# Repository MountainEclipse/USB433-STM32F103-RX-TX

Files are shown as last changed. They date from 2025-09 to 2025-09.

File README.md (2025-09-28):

# USB433 - Sniff and Transmit

USB-connected, STM32F103-based 433.92MHz module with asynchronous RX sniffing for OOK protocol

<hr>

*Github Repo: <a href="https://github.com/MountainEclipse/USB433-STM32F103-RX-TX" target="_blank">USB433</a> by <a href="https://github.com/MountainEclipse" target="_blank">MountainEclipse (TimeHack)</a>*

*Assembly Instructable: <a href="https://www.instructables.com/USB433-Sniff-Transmit-OOK-43392-MHz/" target="_blank">USB433 - Sniff & Transmit OOK 433.92 MHz</a>*

<hr>

This project allows you to passively sniff On-Off-Keyed (OOK) signals in the environment - up to 64 bits in length - and transmit OOK messages via a USB-connected radio module. Originally designed to operate 433.92 MHz wireless outlet switches, this module can also receive weather station data and mimic other 433 MHz codes.

Designed to operate on a custom circuit board, this project should equally work with the hobby-friendly BluePill STM32F103 board with jumper wires to OOK RX/TX modules. All design and firmware files are provided as is, for personal hobbyist use under Creative Commons 4.0 Attribution, Non-Commercial (CC BY-NC) international license.

The following is a list of everything you need to make this project:
<ul>
  Hardware:

<li>STM32F103 Microcontroller (the STM32 Blue Pill can work; just pay attention to pinouts)</li>
<li>433 MHz OOK Receiver and Transmitter (I used SRX882 and STX882)</li>
<li>Optional: 3D Printer for printing the enclosure</li>
<li>Optional: LED's for user feedback</li>
<li>4x M3x12 hex socket screws</li>
<li>4x M3 hex nuts</li>
</ul>
<ul>
Software:
<li>KiCAD 6.0 (If you're modifying the PCB or generating the DRL files for PCB fabrication)</li>
<li>STM32CubeIDE (for flashing the STM32 with ease)</li>
<li>Optional: Hercules Setup Utility (for testing serial commands)</li>
</ul>

<hr>
For instructions on assembly, flashing, and testing, please visit the project Instructable <a href="https://www.instructables.com/USB433-Sniff-Transmit-OOK-43392-MHz/" target="_blank">here</a>

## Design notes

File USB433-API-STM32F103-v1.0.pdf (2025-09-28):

# STM32F103 433MHz RX/TX Module

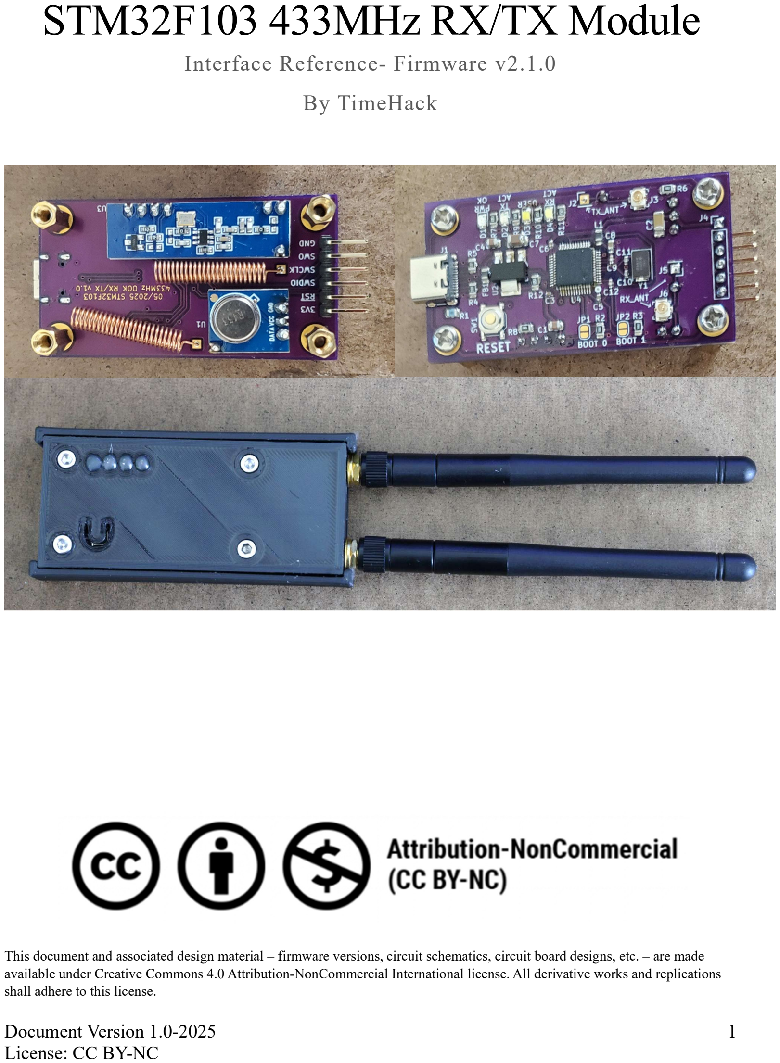
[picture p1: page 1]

Document Version 1.0-2025 | 1
License: CC BY-NC

Interface Reference- Firmware v2.1.0 By TimeHack

This document and associated design material – firmware versions, circuit schematics, circuit board designs, etc. – are made available under Creative Commons 4.0 Attribution-NonCommercial International license. All derivative works and replications shall adhere to this license.

Document Version 1.0-2025 | 2

## Summary

This module is a USB-driven RF sniffer and transmitter module based around the SRX882S and STX882 Superheterodyne Receiver/Transmitter pair and an STM32F103C8T6 processor. Both receive and transmit operations are highly configurable by the user via USB serial communications port.

The module is designed to connect to a USB host device with the default Communications Device Class (CDC) driver. A user can then open a serial port to the module to configure receive/transmit parameters, command transmissions, and receive asynchronous messages about sent and received transmissions.

When idle, the module passively listens for changes to the data output from the SRX882S Receiver, collecting information about on/off pulse widths and periods and correlating received data to measure repetitions of bit sequences (“words”) to indicate a data transmission. Each correlated word (up to 64 bits in length) then gets communicated to the USB host with additional information regarding word length, waveform timings (high/low/period durations), and receiver parameters (logic assumption, whether an initial sync bit is ignored). The module can be configured to listen for words within a range of lengths, from 1 to 64 bits.

The module can transmit messages up to 64 bits in length with an optional leading synchronizing bit, which is a long-high duration pulse (typically a 0 for standard logic interpretations). That synchronizing bit is automatically added to the transmission payload if the ignoresyncbit flag is set false (0).

The module includes LED’s for user feedback. One indicates 3.3V available to the processor core and RX/TX modules; a second indicates USB activity and illuminates upon user commands to the units and asynchronous messages from the module; the third indicates transmission activity, and the fourth represents whether the receiver module is active.

Document Version 1.0-2025 | 3

## System Status Codes

The internal system status variable consists of a single, 32-bit unsigned integer, divided into four bytes. Values from bits 0-7 are reserved for USB status codes; bits 8-15 represent transmission status codes; bits 16-23 are for receiver status codes; and bits 24-31 are reserved for future expansion.

A complete listing of utilized status codes are shown in Table 1. Status codes beginning with USB_CC are used in USB responses to commands, whereas status codes starting with RX and TX are used in asynchronous messages to the USB host. The status code will always be the first value in a message string from the module. See the following subsections for detail on each status code.

Table 1: Hex and Decimal codes for system statuses
Code Identifier | Byte Value (Hex) | Status Value (Decimal)
USB_CC_OK | 0x00 | 0
USB_CC_BUSY | 0x01 | 1
USB_CC_UNKNOWN | 0x10 | 16
USB_CC_BAD_VALUE | 0x20 | 32
USB_CC_BAD_PARAM | 0x30 | 48
USB_CC_MISSING_PARAM | 0x31 | 49
TX_BUFFER_EMPTY | 0x0100 | 256
TX_PREP_FAILED | 0x0200 | 512
TX_COMPLETE | 0x0400 | 1024
RX_WORD_AVAILABLE | 0x010000 | 65536

### USB_CC_OK

Response provided after successful get or set USB operation. When setting parameters, a response of ‘0 OK’ will be sent. For getting parameters, a response ‘0 <parameter> <value>’ will be sent, where ‘parameter’ is the final word of the command (e.g. ‘mode’ for ‘rx mode’; or, ‘short’ for ‘tx time short’) and ‘value’ is the current parameter value. Single-word commands return ‘0 <value>’ for the current parameter value (e.g. ‘version’ returns ‘0 2.1.0’; and, ‘status’ returns ‘0 <status>’).

### USB_CC_BUSY

Response provided when the module is busy processing and cannot execute the requested command. As of the current firmware version (2.1.0), this response is only provided if the transmission word buffer is full and cannot accept another call to ‘tx [word]’. Such a response is only the status code.

Document Version 1.0-2025 | 4

### USB_CC_UNKNOWN

Response provided when the provided command is not recognized – essentially if the first word in the command string is not ‘rx’, ‘tx’, ‘status’, or ‘version’. Response follows structure: ‘<status> <command>’ where ‘command’ is the unrecognized part of the command string.

### USB_CC_BAD_VALUE

Response provided when the value given for setting a parameter is invalid for the command. The value may be out of the range limitations internal to the system or the wrong data type. Response format follows ‘<status> <invalid_value>’, where ‘invalid_value’ is the problematic value.

### USB_CC_BAD_PARAM

Response provided when parts of the command are recognized, but a subcommand is invalid. Response structure is formatted as ‘<status> <bad_subcommand>’ where ‘bad_subcommand’ is the problematic string. For example, if the command ‘rx data’ is passed, the command ‘rx’ is recognized, but ‘data’ is invalid, so the module will respond with ’48 data’.

### USB_CC_MISSING_PARAM

Response to an incomplete command, where all parts are recognized, but it doesn’t correspond to an action for the module to perform due to a missing subcommand or parameter. Response is strictly the status code.

### TX_BUFFER_EMPTY

Status indicating there are no pending transmissions in the buffer. Only available upon request by the USB host using command ‘status’. Synonymous with an idle system status during normal operation.

### TX_PREP_FAILED

A status which should never occur, provided adequate parsing during command processing. This will asynchronously be sent to the USB host if the transmission word being processed for broadcast contains invalid characters – i.e. values that are not ‘0’ or ‘1’. This state is included as a built-in secondary safety against core faults from processing invalid words. Message structure with this asynchronous message follows ‘<status> <tx_word>’, with ‘tx_word’ being the problematic broadcast word.

### TX_COMPLETE

Status message that will be asynchronously sent to the USB host to indicate a transmission has completed successfully. Message structure follows ‘<status> <tx_word>’, with ‘tx_word’ being the binary string successfully broadcast. This string will include any automatically prepended sync bits based on the setting ‘tx ignoresyncbit’.

Document Version 1.0-2025 | 5

### RX_WORD_AVAILABLE

Status message to be asynchronously sent to the USB host when a transmission is received that matches the settings configuration for the receive channel of the module. Detections / matches will only be triggered if all of the following are met:
- Detected bit sequence longer than ‘rx word minlength’
- Detected bit sequence shorter than ‘rx word maxlength’
- Detected repetition of bit sequence greater than or equal to ‘rx word matchcount’
- Time between last bit sequence received and the newest received code is less than
‘rx word timeout’ microseconds. All sequences received prior to an elapsed word reception gap of this timeout will be used to check for word repetitions.
- A bit sequence repetition for this code has not already been transmitted to the USB host in the last ‘rx word timeout’ microseconds.

These conditions mean that for a broadcast word which might be transmitted 10 times to ensure the receiving device reliably receives the word, the USB host device will not be overwhelmed with messages each time a repetition more than ‘rx word matchcount’ occurs in that repeated burst of word transmissions. For each burst, only one transmission of a repeated word will be sent.

Document Version 1.0-2025 | 6

## USB Serial Commands

The module accepts a diversity of commands for getting/setting on-board parameters. Each valid command is defined below. Where the command includes a data type in ‘< >’ at the end, the bracketed value is optional. Including that value uses the write function of that command, and omitting it will execute the read function of that command.

All successful ‘read’ operations will return a message structure
<status> <final_subcommand> <value>
where ‘status’ is USB_CC_OK, ‘final_subcommand’ is the last non-value word of the command string, and ‘value’ is the current parameter value.

All ‘write’ operations, if successful, will return a message structure
<status> OK
with ‘status’ being the value of USB_CC_OK.

Failure statuses will be returned as applicable as defined in the System Status Codes section, and according to limitations described below in the respective commands.

### version

(READ ONLY)
Return the installed firmware version string in format <major>:<minor>:<tweak> (present as of 2.1.0). Major changes overhaul major system operations (core behavior of RX/TX, etc.) which are not compatible with older versions of the firmware; minor changes correspond to compatibility with older firmware versions, but with added features; tweaks are small updates which do not impact interface between the USB host and module, but which modify module behaviors not seen by the user.

### status

(READ ONLY)
Return the current system 'status' value. Status is a 32-bit (4-byte) code with possible values defined in Table 1 in the section System Status Codes.

### rx mode <0:1:2>

(READ / WRITE)
Get or set the current receiver mode.
- 0 = always off: do not listen for asynchronous broadcasts
- 1 = always on: always listen for broadcasts, even during this module’s broadcasts
- 2 = automatic: disable broadcast detection during this module’s broadcasts (DEFAULT)

Default value: 2 (automatic)
Minimum value: 0
Maximum value: 2

Document Version 1.0-2025 | 7

### rx bitperiod <uint32_t>

(READ / WRITE)
Get or set the maximum bit period, in microseconds. This acts as a timeout during broadcast receptions which allows for processing the data buffer. Due to how OOK broadcasts are structured (with a moderate delay between word transmission repetitions), the most efficient execution for the internal system includes this setting being tuned according to the expected bit period timing of the signal to be received.

Default value: 5000 microseconds (5 ms).
Minimum value: 0 (not recommended)
Maximum value: UINT32_MAX (not recommended)

### rx word matchcount <uint8_t>

(READ / WRITE)
Set the minimum number of matching received word transmissions to trigger an asynchronous RX_WORD_RECEIVED message. This number of repetitions indicates the reception as a “valid” word in order to filter erroneous receptions by the system through corruptions or interference with other signals. Maximum value defined by the length of the data correlation buffer.

Default value: 3
Minimum value: 0
Maximum value: 12

### rx word minlength <uint8_t>

(READ / WRITE)
Get or set the minimum word length (in bits) to use in correlating received data. Any words shorter than this limit get discarded. Maximum limit defined by ‘rx word maxlength’.

Default value: 8
Minimum value: 0
Maximum value: rx word maxlength

### rx word maxlength <uint8_t>

(READ / WRITE)
Get or set the maximum word length (in bits) to use in correlating received data. Any words longer than this limit get discarded. Minimum limit defined by ‘rx word minlength’. Maximum limit set by maximum word buffer length.

Default value: 64
Minimum value: rx word minlength
Maximum value: 64

Document Version 1.0-2025 | 8

### rx word timeout <uint32_t>

(READ / WRITE)
Get or set the timeout, in microseconds, for the data correlation buffer which caches the most recently received bit sequences. Once this timeout occurs, the buffer will be cleared. Minimum limit defined by ‘rx bitperiod’.

Default value: 100,000 (100 ms)
Minimum value: rx bitperiod
Maximum value: 5,000,000 (5 s)

### rx ignoresyncbit <0:1>

(READ / WRITE)
Get or set whether the synchronizing bit (first bit received in sequence which sets the receiver state) should be included in the bit sequence to be sent to the USB host.
- 0 = no; include sync bit.
- 1 = yes; omit sync bit.

Default value: 1 (omit sync bit)
Minimum value: 0
Maximum value: 1

### rx logic <0:1>

(READ / WRITE)
Get or set the logic interpretation by the receiver – i.e. how high-low relative durations should be interpreted as bits.
- 0 = long high with short low corresponds to bit ‘0’
- 1 = long high with short low corresponds to bit ‘1’

Default value: 0
Minimum value: 0
Maximum value: 1

### tx time short <uint16_t>

(READ / WRITE)
Get or set the timing, in microseconds, of a short pulse. Used for both logic ‘0’ and ‘1’ short part of bit transmission. Must be less than ‘tx time long’ or UINT16_MAX / 2, whichever is less. The sum of ‘tx time short’ and ‘tx time long’ determines bit period for transmission.

Default value: 300
Minimum value: 0 (not recommended)
Maximum value: tx time long

Document Version 1.0-2025 | 9

### tx time long <uint16_t>

(READ / WRITE)
Get or set the timing, in microseconds, or a long pulse. Used for both logic ‘0’ and ‘1’ long part of bit transmission. Must be greater than ‘tx time short’ and less than UINT16_MAX / 2. The sum of ‘tx time short’ and ‘tx time long’ determines bit period for transmission.

Default value: 700
Minimum value: tx time short
Maximum value: UINT16_MAX / 2

### tx delay frame <uint32_t>

(READ / WRITE)
Get or set the time delay, in microseconds, between sequential transmissions of words within the same frame. Each word transmitted is considered a ‘frame, and is repeated ‘tx repeat’ number of times. This is the delay between each repetition of transmission.

Default value: 6600 (6.6 ms)
Minimum value: [(tx time short) + (tx time long)] (1 bit period)
Maximum value: 50*[(tx time short) + (tx time long)] (50 bit periods)

### tx delay burst <uint32_t>

(READ / WRITE)

Get or set the time delay, in microseconds, between sequential broadcasts of buffered words. Each broadcast is considered a ‘burst’ and consists of ‘tx repeat’ number of frames. This is the delay between different broadcast bursts, and controls how fast sequential broadcast requests can be executed.

Default value: 100,000 (100 ms)
Minimum value: [(tx time short) + (tx time long)]
Maximum value: 60,000,000 (60 s)

### tx ignoresyncbit <0:1>

(READ / WRITE)
Get or set whether a sync bit should be prepended to the bit sequence to transmit. If this is value 1 (true), the user should compensate for sync bit inclusion in the transmitted bit sequence.
- 0 = prepend a ‘0’ bit to the transmission bit sequence
- 1 = do not prepend a ‘0’ to the transmission bit sequence

Default value: 0
Minimum value: 0
Maximum value: 1

Document Version 1.0-2025 | 10

### tx repeat <uint8_t>

(READ / WRITE)
Get or set how many times a bit sequence frame gets repeated in a burst. One frame will always be transmitted. This is the number of repetitions of transmissions.

Default value: 7
Minimum value: 0
Maximum value: 100

### tx logic <0:1>

(READ / WRITE)
Get or set the logic to be used for interpreting commanded broadcasts.
- 0 = ‘0’ means long high with short low
- 1 = ‘1’ means long high with short low

Default value: 0
Minimum value: 0
Maximum value: 1

### tx [sequence of 0:1]

(WRITE ONLY)
Queue the broadcast of a bit sequence, up to 64 bits. Up to 5 messages can be simultaneously queued for transmission and will be processed according to the time separation of ‘tx delay burst’.

Document Version 1.0-2025 | 11

## Asynchronous Messages

Three message types occur asynchronously with user commands. These indicate a broadcast reception, a failure to prepare a transmission burst, or successful completion of a transmission burst. Details on each message structure are below.

### Broadcast Received

Message to indicate a valid broadcast was received. See System Status Codes -> RX_WORD_AVAILABLE for more information on how received broadcasts are validated. The message format for this follows:
<status> word:[0:1] len:<word_len> long_us:<long> short_us:<short> period_us:<period> logic:<logic> ignoresync:<sync>
where:
- ‘status’ is RX_WORD_AVAILABLE
- ‘word_len’ is the length of the received bit sequence
- ‘long’ is the average of long pulse durations across all received matching bit sequences
- ‘short’ is the average of short pulse durations across all received matching bit sequences
- ‘period’ is the average period duration across all received matching bit sequences
- ‘logic’ is the interpretation used to present ‘0’ and ‘1’ characters. See ‘rx logic’ for more information
- ‘sync’ is whether the first received bit (sync bit) is included in the received message. See ‘rx ignoresyncbit’ for more information.

### Transmission Preparation Failed

Message to indicate an error with translating the commanded transmission bit sequence into a sequence of pulses. Namely, a character other than ‘0’ or ‘1’ made it to the buffered bit sequence. Message structure follows:
<status> [word]
where ‘status’ is TX_PREP_FAILED, and ‘word’ is the string which failed to translate into pulses.

### Message Transmitted

Message ton indicate successful transmission of a bit sequence burst. Message structure follows: <status> [word]
where ‘status’ is TX_COMPLETE, and ‘word’ is the binary string successfully transmitted, including prepended sync bit, as applicable.

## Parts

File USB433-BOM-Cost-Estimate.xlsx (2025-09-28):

Tool: | Eeschema (6.0.11)
Component Count: | 44
Ref | Qnty | Value | Cmp name | Footprint | Description | Price | Cost | Vendor | Link
C1, C4, | 2 | 10uF | C | Capacitor_SMD:C_0805_2012Metric | Unpolarized capacitor | $0.0104 | $0.0208 | LCSC | https://www.lcsc.com/product-detail/Multilayer-Ceramic-Capacitors-MLCC-SMD-SMT_Samwha-Capacitor-CS2012X5R106K100NRE_C513765.html
C2, | 1 | 100u | C_Polarized_US | Capacitor_SMD:C_1206_3216Metric_Pad1.33x1.80mm_HandSolder | Polarized capacitor, US symbol | $0.1802 | $0.1802 | LCSC | https://www.lcsc.com/product-detail/Multilayer-Ceramic-Capacitors-MLCC-SMD-SMT_HRE-CGA1206X5R107K6R3NT_C6119960.html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
C3, C5, C6, C9, C12, | 5 | 100nF | C | Capacitor_SMD:C_0402_1005Metric | Unpolarized capacitor | $0.0017 | $0.0085 | LCSC | https://www.lcsc.com/product-detail/Multilayer-Ceramic-Capacitors-MLCC-SMD-SMT_YAGEO-CC0402JRX7R7BB104_C541464.html
C7, | 1 | 22uF | C | Capacitor_SMD:C_1206_3216Metric | Unpolarized capacitor | $0.0248 | $0.0248 | LCSC | https://www.lcsc.com/product-detail/Multilayer-Ceramic-Capacitors-MLCC-SMD-SMT_Samwha-Capacitor-CS3216X5R226M160NRI_C5177178.html
C8, | 1 | 1uF | C | Capacitor_SMD:C_0603_1608Metric | Unpolarized capacitor | $0.0052 | $0.0052 | LCSC | https://www.lcsc.com/product-detail/Multilayer-Ceramic-Capacitors-MLCC-SMD-SMT_Samsung-Electro-Mechanics-CL10A105KB8NNNC_C15849.html
C10, C11, | 2 | 30p | C | Capacitor_SMD:C_0402_1005Metric | Unpolarized capacitor | $0.0012 | $0.0024 | LCSC | https://www.lcsc.com/product-detail/Multilayer-Ceramic-Capacitors-MLCC-SMD-SMT_FH-Guangdong-Fenghua-Advanced-Tech-0402CG300J500NT_C1570.html
D1, D3, D4, | 3 | PWR_OK, DEBUG, RED | LED | LED_SMD:LED_0805_2012Metric | Light emitting diode | $0.0057 | $0.0171 | LCSC | https://www.lcsc.com/product-detail/LED-Indication-Discrete_XINGLIGHT-XL-2012SURC_C965812.html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
D2, | 1 | BLUE | LED | LED_SMD:LED_0805_2012Metric | Light emitting diode | $0.0239 | $0.0239 | LCSC | https://www.lcsc.com/product-detail/LED-Indication-Discrete_BrtLed-Bright-LED-Elec-BL-HB335B-TRB-6_C189307.html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
FB1, | 1 | FerriteBead | FerriteBead | Resistor_SMD:R_0805_2012Metric | Ferrite bead | $0.0041 | $0.0041 | LCSC | https://www.lcsc.com/product-detail/Ferrite-Beads_MetalLions-MLB2012F-391T_C2844594.html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
J1, | 1 | USB-C | USB_C_Receptacle | Connector_USB:USB_C_Receptacle_G-Switch_GT-USB-7010ASV | USB Full-Featured Type-C Receptacle connector | $0.0761 | $0.0761 | LCSC | https://www.lcsc.com/product-detail/USB-Connectors_G-Switch-GT-USB-7010ASV_C2988369.html
J2, J5 | 2 | TX_ANT_EXT, RX_ANT_EXT | Conn_01x01 | Connector_PinHeader_2.54mm:PinHeader_1x01_P2.54mm_Vertical | Generic connector, single row, 01x01, script generated (kicad-library-utils/schlib/autogen/connector/) |  | $0.0000
J3, J6 | 2 | TX_U.FL, RX_U.FL | U_FL-R-SMT_10_ | digikey-footprints:Coax_Conn_U.FL | CONN U.FL RCPT STR 50 OHM SMD | $0.0331 | $0.0662 | LCSC | https://www.lcsc.com/product-detail/Coaxial-Connectors-RF_BAT-WIRELESS-BWU-FL-IPEX1_C5137195.html?s_z=n_UFL
J4, | 1 | DEBUG | Conn_01x06 | Connector_PinHeader_2.54mm:PinHeader_1x06_P2.54mm_Vertical | Generic connector, single row, 01x06, script generated (kicad-library-utils/schlib/autogen/connector/) |  | $0.0000
JP1, | 1 | BOOT0 | SolderJumper_2_Open | Jumper:SolderJumper-2_P1.3mm_Open_RoundedPad1.0x1.5mm | Solder Jumper, 2-pole, open |  | $0.0000
JP2, | 1 | BOOT1 | SolderJumper_2_Open | Jumper:SolderJumper-2_P1.3mm_Open_RoundedPad1.0x1.5mm | Solder Jumper, 2-pole, open |  | $0.0000
L1, | 1 | 27uH | L | Inductor_SMD:L_0805_2012Metric | Inductor | $0.0233 | $0.0233 | LCSC | https://www.lcsc.com/product-detail/Inductors-SMD_XR-XRCM2012J270K-A005_C41368706.html?s_z=n_27uH%2520inductor
R1, | 1 | 1M | R_US | Resistor_SMD:R_0805_2012Metric | Resistor, US symbol | $0.0077 | $0.0077 | LCSC | https://www.lcsc.com/product-detail/Chip-Resistor-Surface-Mount_KOA-Speer-Elec-RK73H2ATTD1004F_C276217.html
R2, R3, R6, R8, | 4 | 10k | R_US | Resistor_SMD:R_0805_2012Metric | Resistor, US symbol | $0.0098 | $0.0392 | LCSC | https://www.lcsc.com/product-detail/Chip-Resistor-Surface-Mount_KOA-Speer-Elec-RK73H2ATTD1002F_C276215.html
R4, R5, | 2 | 5k1 | R_US | Resistor_SMD:R_0805_2012Metric | Resistor, US symbol | $0.0078 | $0.0156 | LCSC | https://www.lcsc.com/product-detail/Chip-Resistor-Surface-Mount_UNI-ROYAL-Uniroyal-Elec-HP05W3F5101T5E_C2759278.html
R7, R9, R10, R11, R12, | 5 | 1k5 | R_US | Resistor_SMD:R_0805_2012Metric | Resistor, US symbol | $0.0102 | $0.0510 | LCSC | https://www.lcsc.com/product-detail/Chip-Resistor-Surface-Mount_YAGEO-RC0805FR-7W1K5L_C606178.html
SW1, | 1 | RESET | SW_Push | User_Custom:SW_Push_1P1T_W6.8mm_H4.6mm | Push button switch, generic, two pins | $0.0122 | $0.0122 | LCSC | https://www.lcsc.com/product-detail/Tactile-Switches_BZCN-TSC006A1526A_C2888882.html
U1, | 1 | STX882S | STX882S | User_Custom:STX882-THT |  | $1.8738 | $1.8738 | Amazon | https://www.amazon.com/AITIAO-Wireless-Control-Transmitter-Receiver/dp/B09KXKSR3V/ref=sr_1_2?sr=8-2
U2, | 1 | AZ1117CH-3.3TRG1 | AZ1117CH-3_3TRG1 | digikey-footprints:SOT-223 | IC REG LINEAR 3.3V 800MA SOT223 | $0.0722 | $0.0722 | LCSC | https://www.lcsc.com/product-detail/Linear-Voltage-Regulators-LDO_Diodes-Incorporated-AZ1117H-3-3TRG1_C110474.html
U3, | 1 | SRX882S | SRX882S | User_Custom:SRX882-THT |  | $1.8738 | $1.8738 | Amazon | https://www.amazon.com/AITIAO-Wireless-Control-Transmitter-Receiver/dp/B09KXKSR3V/ref=sr_1_2?sr=8-2
U4, | 1 | STM32F103C8Tx | STM32F103C8Tx | Package_QFP:LQFP-48_7x7mm_P0.5mm | ARM Cortex-M3 MCU, 64KB flash, 20KB RAM, 72MHz, 2-3.6V, 37 GPIO, LQFP-48 | $1.7009 | $1.7009 | ARROW | https://www.arrow.com/en/products/stm32f103c8t6/stmicroelectronics
Y1, | 1 | 8M, 20pF | Crystal | Crystal:Crystal_SMD_5032-2Pin_5.0x3.2mm | Two pin crystal | $0.2056 | $0.2056 | LCSC | https://www.lcsc.com/product-detail/Crystals_Yangxing-Tech-X50328MSB2GI_C115962.html
 |  |  |  |  |  | Components | $6.3045
 |  |  |  |  |  | Board Fab | $4.7667
 |  |  |  |  |  | Stencil | $9.6900 | $29.07
 |  |  |  |  |  |  | $20.7612 |  |  | PCB Fab | Round | Bulk Cost | Qty
 |  |  |  |  |  |  |  |  |  |  | 1 | $14.30 | 3
 |  |  |  |  |  |  |  |  |  |  | 2
 |  |  |  |  |  |  |  |  |  |  | 3
 |  |  |  |  |  |  |  |  |  |  | 4
 |  |  |  |  |  |  |  |  |  |  | 5
 |  |  |  |  |  |  |  |  |  |  | 6
 |  |  |  |  |  |  |  |  |  |  | 7
 |  |  |  |  |  |  |  |  |  |  | 8
 |  |  |  |  |  |  |  |  |  |  | 9

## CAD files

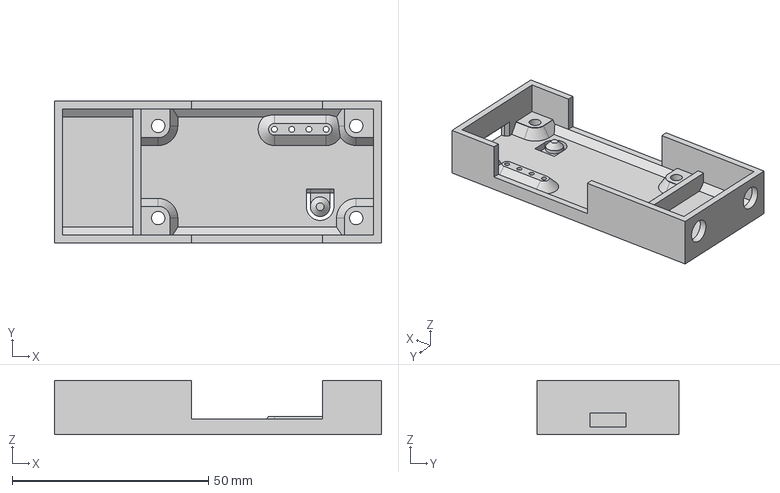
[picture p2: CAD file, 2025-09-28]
USB433-Enclosure-CAD/Bottom.step
83.4 x 36.1 x 13.8 mm

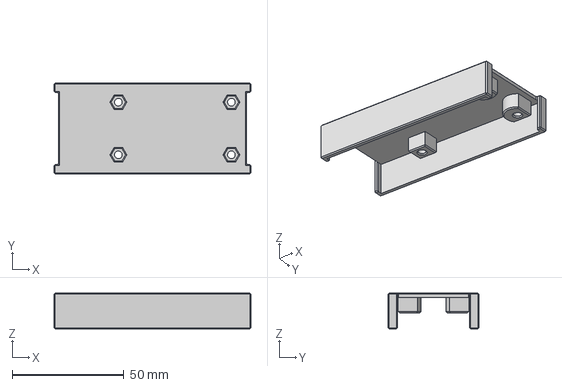
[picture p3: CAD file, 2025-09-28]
USB433-Enclosure-CAD/Top.step
88.0 x 40.7 x 16.0 mm

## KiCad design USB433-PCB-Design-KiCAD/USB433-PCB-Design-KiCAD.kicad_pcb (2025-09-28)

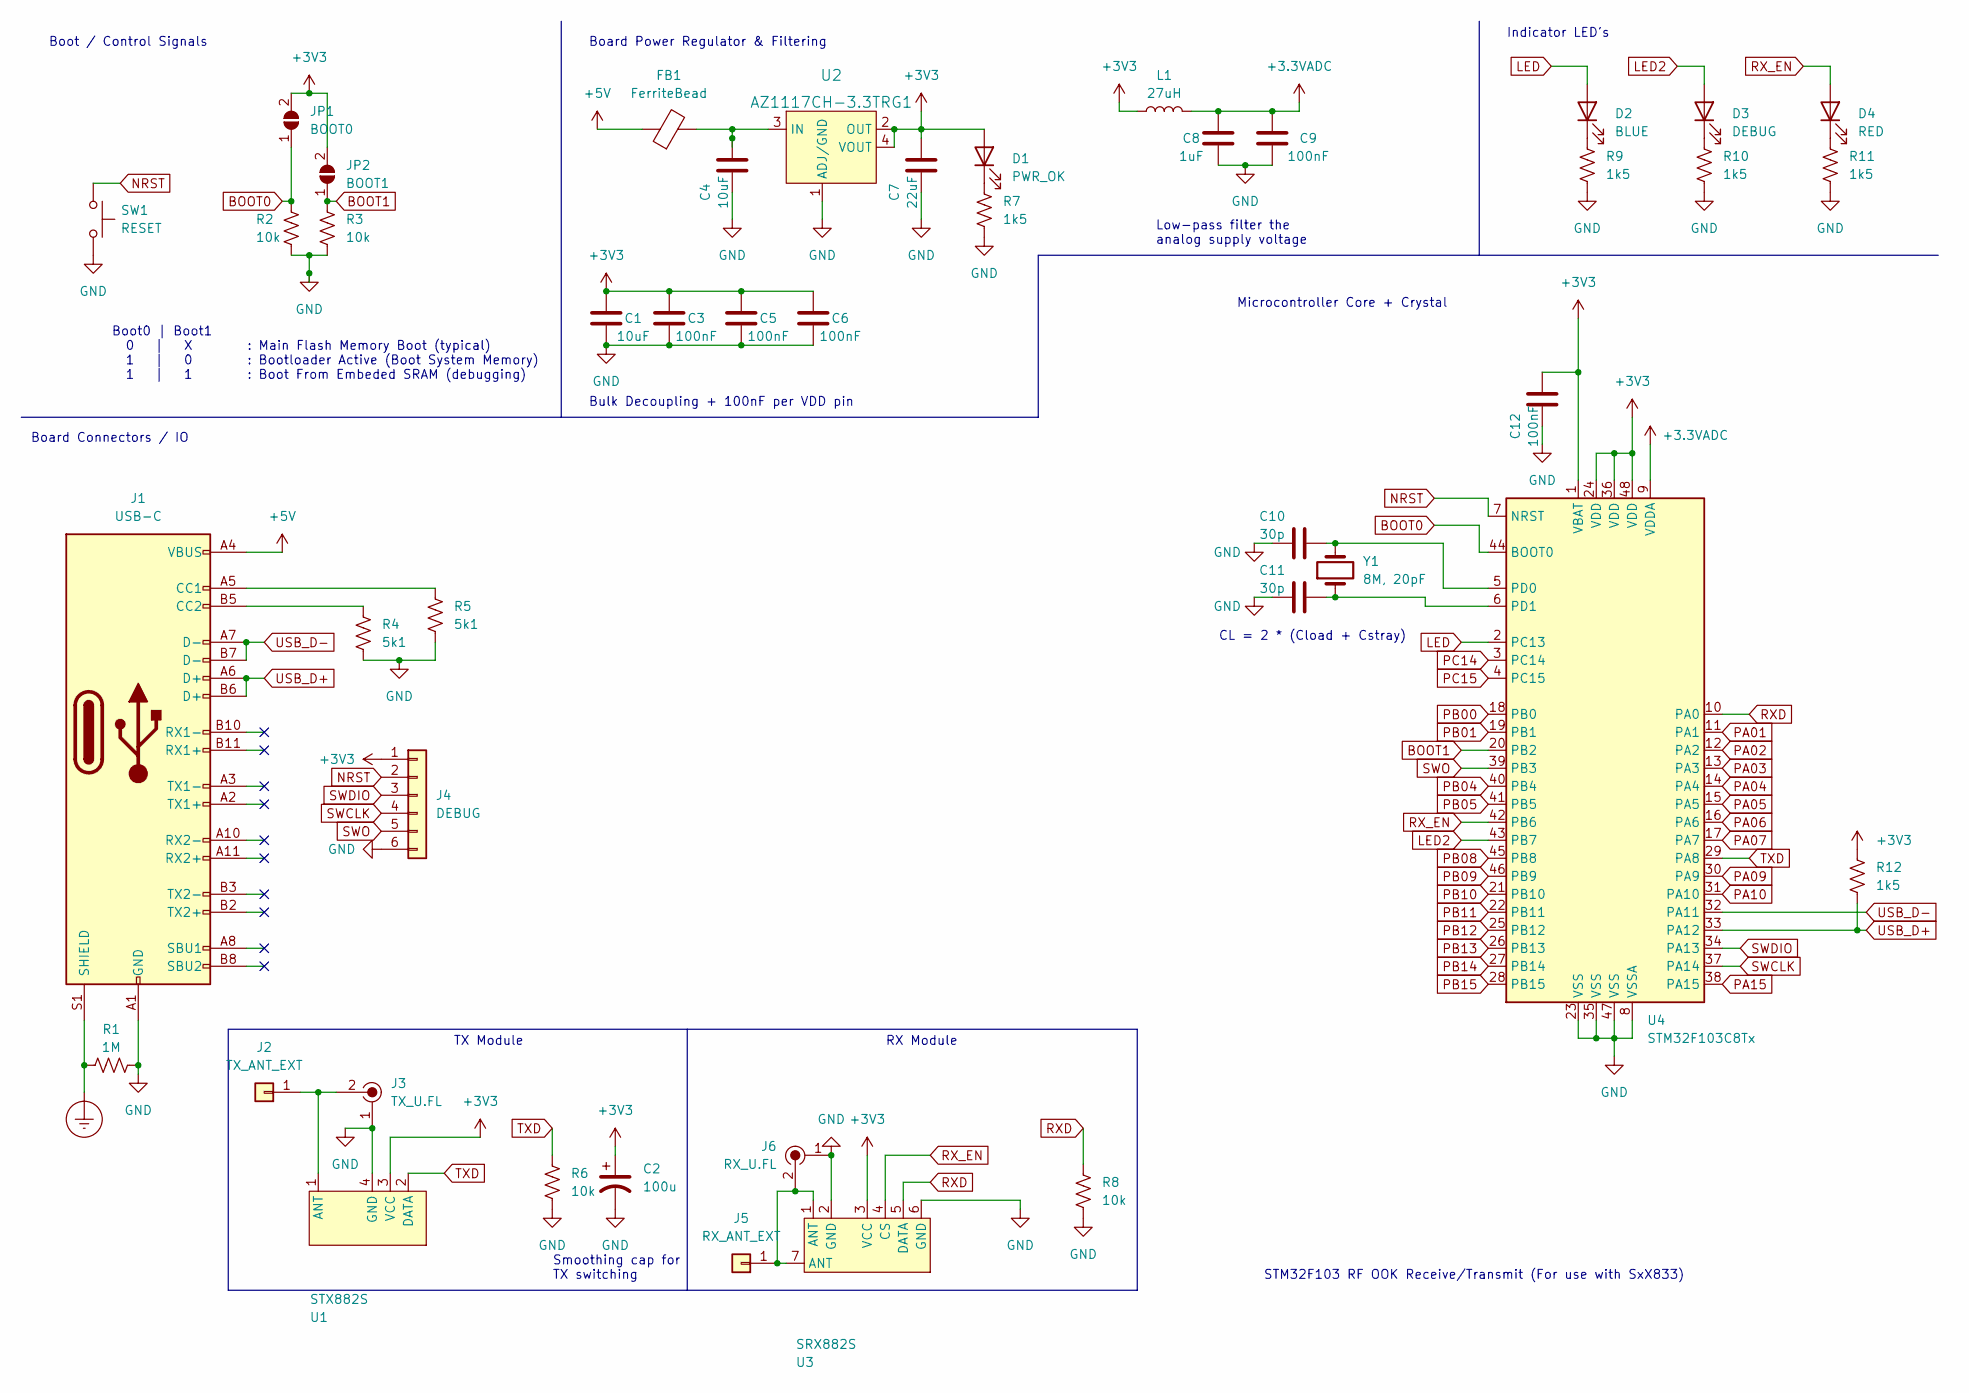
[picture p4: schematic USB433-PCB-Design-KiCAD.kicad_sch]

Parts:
C1, C4: 10uF; C_0805_2012Metric
C2: 100u; C_1206_3216Metric_Pad1.33x1.80mm_HandSolder
C3, C5, C6, C9, C12: 100nF; C_0402_1005Metric
C7: 22uF; C_1206_3216Metric
C8: 1uF; C_0603_1608Metric
C10, C11: 30p; C_0402_1005Metric
D1: PWR_OK; LED_0805_2012Metric
D2: BLUE; LED_0805_2012Metric
D3: DEBUG; LED_0805_2012Metric
D4: RED; LED_0805_2012Metric
FB1: FerriteBead; R_0805_2012Metric
J1: USB-C; USB_C_Receptacle_G-Switch_GT-USB-7010ASV
J2: TX_ANT_EXT; PinHeader_1x01_P2.54mm_Vertical
J3: TX_U.FL; Coax_Conn_U.FL; MPN U.FL-R-SMT(10); Digi-Key_PN H9161CT-ND
J4: DEBUG; PinHeader_1x06_P2.54mm_Vertical
J5: RX_ANT_EXT; PinHeader_1x01_P2.54mm_Vertical
J6: RX_U.FL; Coax_Conn_U.FL; MPN U.FL-R-SMT(10); Digi-Key_PN H9161CT-ND
JP1: BOOT0; SolderJumper-2_P1.3mm_Open_RoundedPad1.0x1.5mm
JP2: BOOT1; SolderJumper-2_P1.3mm_Open_RoundedPad1.0x1.5mm
L1: 27uH; L_0805_2012Metric
R1: 1M; R_0805_2012Metric
R2, R3, R6, R8: 10k; R_0805_2012Metric
R4, R5: 5k1; R_0805_2012Metric
R7, R9, R10, R11, R12: 1k5; R_0805_2012Metric
SW1: RESET; SW_Push_1P1T_W6.8mm_H4.6mm
U1: STX882S; STX882-THT
U2: AZ1117CH-3.3TRG1; SOT-223; MPN AZ1117CH-3.3TRG1; Digi-Key_PN AZ1117CH-3.3TRG1DICT-ND
U3: SRX882S; SRX882-THT
U4: STM32F103C8Tx; LQFP-48_7x7mm_P0.5mm
Y1: 8M, 20pF; Crystal_SMD_5032-2Pin_5.0x3.2mm

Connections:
+3.3VADC: C8.2, C9.2, L1.2, U4.9 (VDDA)
+3V3: C1.2, C2.1, C3.2, C5.2, C6.2, C7.2, C12.2, D1.2 (A), J4.1, JP1.2 (B), JP2.2 (B), L1.1, R12.2, U1.3 (VCC), U2.2 (OUT), U2.4 (VOUT), U3.3 (VCC), U4.1 (VBAT), U4.24 (VDD), U4.36 (VDD), U4.48 (VDD)
+5V: FB1.1, J1.A4 (VBUS), J1.A9 (VBUS), J1.B4 (VBUS), J1.B9 (VBUS)
BOOT0: JP1.1 (A), R2.2, U4.44 (BOOT0)
BOOT1: JP2.1 (A), R3.1, U4.20 (PB2)
Earth_Protective: J1.S1 (SHIELD), R1.1; also elsewhere on the board
GND: C1.1, C2.2, C3.1, C4.1, C5.1, C6.1, C7.1, C8.1, C9.1, C10.1, C11.1, C12.1, J1.A1 (GND), J1.A12 (GND), J1.B1 (GND), J1.B12 (GND), J3.1, J4.6, J6.1, R1.2, R2.1, R3.2, R4.2, R5.2, R6.2, R7.2, R8.2, R9.2, R10.2, R11.2, SW1.2, U1.4 (GND), U2.1 (ADJ/GND), U3.2 (GND), U3.6 (GND), U4.8 (VSSA), U4.23 (VSS), U4.35 (VSS), U4.47 (VSS)
LED: D2.2 (A), U4.2 (PC13)
LED2: D3.2 (A), U4.43 (PB7)
NRST: J4.2, SW1.1, U4.7 (NRST)
unnamed: C4.2, FB1.2, U2.3 (IN)
unnamed: C10.2, U4.5 (PD0), Y1.2
unnamed: C11.2, U4.6 (PD1), Y1.1
unnamed: D1.1 (K), R7.1
unnamed: D2.1 (K), R9.1
unnamed: D3.1 (K), R10.1
unnamed: D4.1 (K), R11.1
unnamed: J1.A5 (CC1), R5.1
unnamed: J1.B5 (CC2), R4.1
unnamed: J2.1, J3.2, U1.1 (ANT)
unnamed: J5.1, J6.2, U3.1 (ANT), U3.7 (ANT)
PA01: U4.11 (PA1)
PA02: U4.12 (PA2)
PA03: U4.13 (PA3)
PA04: U4.14 (PA4)
PA05: U4.15 (PA5)
PA06: U4.16 (PA6)
PA07: U4.17 (PA7)
PA09: U4.30 (PA9)
PA10: U4.31 (PA10)
PA15: U4.38 (PA15)
PB00: U4.18 (PB0)
PB01: U4.19 (PB1)
PB04: U4.40 (PB4)
PB05: U4.41 (PB5)
PB08: U4.45 (PB8)
PB09: U4.46 (PB9)
PB10: U4.21 (PB10)
PB11: U4.22 (PB11)
PB12: U4.25 (PB12)
PB13: U4.26 (PB13)
PB14: U4.27 (PB14)
PB15: U4.28 (PB15)
PC14: U4.3 (PC14)
PC15: U4.4 (PC15)
RXD: R8.1, U3.5 (DATA), U4.10 (PA0)
RX_EN: D4.2 (A), U3.4 (CS), U4.42 (PB6)
SWCLK: J4.4, U4.37 (PA14)
SWDIO: J4.3, U4.34 (PA13)
SWO: J4.5, U4.39 (PB3)
TXD: R6.1, U1.2 (DATA), U4.29 (PA8)
USB_D+: J1.A6 (D+), J1.B6 (D+), R12.1, U4.33 (PA12)
USB_D-: J1.A7 (D-), J1.B7 (D-), U4.32 (PA11)

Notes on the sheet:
STM32F103 RF OOK Receive/Transmit (For use with SxX833)
Boot0 | Boot1 0 | X : Main Flash Memory Boot (typical) 1 | 0 : Bootloader Active (Boot System Memory) 1 | 1 : Boot From Embeded SRAM (debugging)
TX Module
Indicator LED's
Board Connectors / IO
Boot / Control Signals
RX Module
Smoothing cap for TX switching
CL = 2 * (Cload + Cstray)
Board Power Regulator & Filtering
Bulk Decoupling + 100nF per VDD pin
Microcontroller Core + Crystal
Low-pass filter the analog supply voltage

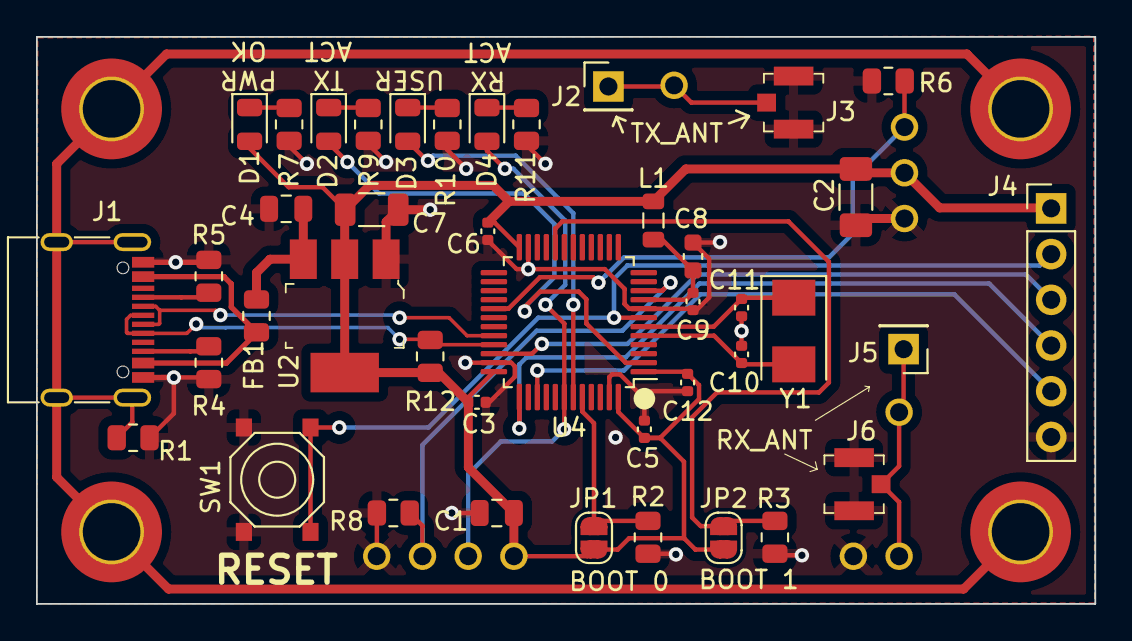
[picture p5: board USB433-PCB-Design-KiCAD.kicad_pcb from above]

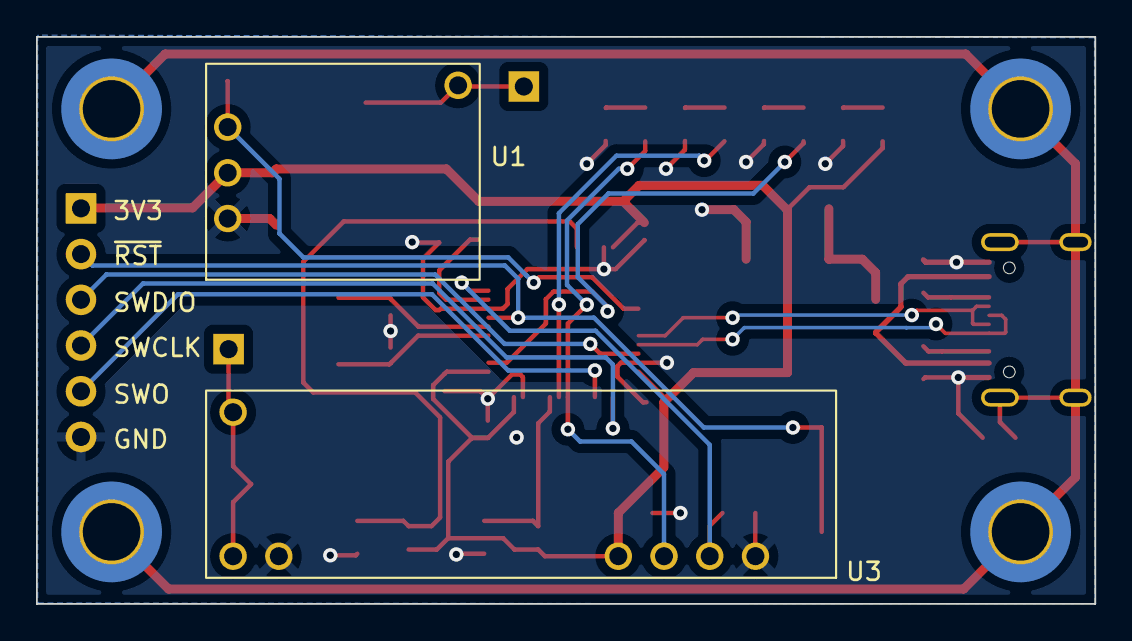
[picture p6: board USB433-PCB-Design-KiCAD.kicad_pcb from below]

Board: 2 copper layers, 58.8 x 31.5 mm, 48 parts (2 on the bottom side), 29 nets.

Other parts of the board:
M3, M3#2, M3#3, M3#4: Mount; MountingHole_3.2mm_M3_DIN965_Pad_TopBottom

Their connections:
Earth_Protective: M3.1, M3#2.1, M3#3.1, M3#4.1; also elsewhere on the board

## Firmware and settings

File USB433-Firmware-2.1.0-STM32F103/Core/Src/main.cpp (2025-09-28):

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
/* Includes ------------------------------------------------------------------*/
#include "main.h"
#include "usb_device.h"

/* USER CODE BEGIN Includes */
#include "core_main.h"

/* USER CODE END Includes */

TIM_HandleTypeDef htim1;
TIM_HandleTypeDef htim2;
DMA_HandleTypeDef hdma_tim1_ch1;

void SystemClock_Config(void);
static void MX_GPIO_Init(void);
static void MX_DMA_Init(void);
static void MX_TIM1_Init(void);
static void MX_TIM2_Init(void);
/**
  * @brief  The application entry point.
  * @retval int
  */
int main(void)
{

  /* MCU Configuration--------------------------------------------------------*/

  /* Reset of all peripherals, Initializes the Flash interface and the Systick. */
  HAL_Init();

  /* Configure the system clock */
  SystemClock_Config();

  /* Initialize all configured peripherals */
  MX_GPIO_Init();
  MX_DMA_Init();
  MX_TIM1_Init();
  MX_TIM2_Init();
  MX_USB_DEVICE_Init();
  /* USER CODE BEGIN 2 */
  int setup = USER_setup();
  if(setup < 0) {
    USER_error();
    return setup;
  }
  /* USER CODE END 2 */

  /* Infinite loop */
  /* USER CODE BEGIN WHILE */
  while (1 && setup == 0) {
	/* USER CODE END WHILE */

	/* USER CODE BEGIN 3 */
	int loop = USER_loop();
	if (loop > 0) {
	  break;
	}
	else if (loop < 0) {
	  USER_error();
	  return loop;
	}
  }
  USER_shutdown();
  /* USER CODE END 3 */
}

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


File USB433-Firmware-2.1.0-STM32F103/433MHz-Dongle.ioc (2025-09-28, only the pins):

Mcu.UserName=STM32F103C8Tx
PA0-WKUP.Signal=S_TIM2_CH1_ETR
PA11.Signal=USB_DM
PA12.Signal=USB_DP
PA13.Signal=SYS_JTMS-SWDIO
PA14.Signal=SYS_JTCK-SWCLK
PA8.Signal=S_TIM1_CH1
PB3.Signal=SYS_JTDO-TRACESWO
PB6.GPIO_Label=RX_EN
PB6.Signal=GPIO_Output
PB7.GPIO_Label=TX_ACT
PB7.Signal=GPIO_Output
PC13-TAMPER-RTC.GPIO_Label=USB_ACT
PC13-TAMPER-RTC.Signal=GPIO_Output
PD0-OSC_IN.Signal=RCC_OSC_IN
PD1-OSC_OUT.Signal=RCC_OSC_OUT

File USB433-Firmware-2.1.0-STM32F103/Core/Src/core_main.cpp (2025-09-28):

/*
 * core_main.cpp
 *
 *  Created on: May 14, 2025
 *      Author: RM
 */
#include "stm32f1xx_hal.h"
#include "stm32f1xx_hal_tim.h"
#include "usbd_cdc_if.h"

#include "stdio.h"
#include "stdint.h"
#include "string.h"
#include "inttypes.h"

#include "main.h"
#include "core_main.h"
#include "commands.h"
#include "transmitter.h"
#include "receiver.h"

// errors and system status flags
// This status is sectioned into 4 bytes:
// bits  0 -  7: USB response values (not handled directly here)
// bits  8 - 15: Transmitter process status
// bits 16 - 23: Receiver process status
uint32_t status = 0;

// Firmware version string
const char version[] = "2.1.0";

// timeout parameter, in millis, for the USB activity indicator
//   to turn off after last Read or Write activity
uint16_t timeout_ms = 250;

// ================= OOK RX PARAMS ======================



// =================== SYS PARAMS =======================

int USER_setup(void) {
	txInit(&tx); // initialize Tx function
	rxInit(&rx); // initialize Rx function

	// flash on-board LED to indicate system active
	HAL_GPIO_WritePin(USB_ACT_GPIO_Port, USB_ACT_Pin, GPIO_PIN_SET);
	HAL_Delay(500);
	HAL_GPIO_WritePin(USB_ACT_GPIO_Port, USB_ACT_Pin, GPIO_PIN_RESET);

	if (rx.mode > 0) {
		enableRx(); // enable radio receiver
	}
	return 0;
}

/*
 * User-defined loop structure. There are 3 loop return conditions:
 * return 0: loop should continue
 * return >0: loop should terminate, no error handling; program will execute USER_shutdown
 * return <0: loop should terminate, errors to report; program will execute USER_Error
 */
int USER_loop(void) {
	// process any potential USB data received
	processUSB();

	// process updates to current / next transmission
	processTx(&tx, &data);

	// handle system feedback due to transmit status values
	if (((status >> 8) & 0xFF) > TX_BUFFER_EMPTY) {
		memset(usb_tx_buffer, 0, sizeof(usb_tx_buffer));
		// buffer outputs to usb host on tx buffer prep fail or tx complete flags
		if ((status >> 8) & TX_PREP_FAILED) {
			sprintf(usb_tx_buffer, "%" PRIu32 " %s\r\n", status & (TX_PREP_FAILED << 8), tx.buffer[0]);
		} else if ((status >> 8) & TX_COMPLETE) {
			sprintf(usb_tx_buffer, "%" PRIu32 " %s\r\n", status & (TX_COMPLETE << 8), tx.buffer[0]);
		}

		// tx buffer retains tx data until either a fail to buffer or a transmission complete
		// Once either of those conditions are met, shift the buffer over.
		if ((status >> 8) & (TX_PREP_FAILED | TX_COMPLETE)) {
			// shift the tx_buffer to the left
			memmove(tx.buffer, tx.buffer[1], (TX_BUFFER_LEN - 1) * TX_MAX_BITS);
			memset(tx.buffer[TX_BUFFER_LEN - 1], 0, TX_MAX_BITS);
			status &= ~((TX_PREP_FAILED | TX_COMPLETE) << 8); // clear the flags
		}
		pushUSB();
	}

	// process RF received buffer content
	checkRxBuffers();

	// TODO: check for matching received words, and calculate average of observed timings

	// check if the receiver status is non-zero
	if ((status >> 16) & 0xFF) {
		memset(usb_tx_buffer, 0, sizeof(usb_tx_buffer));
		// data received, so transmit to USB host
		if ((status >> 16) & RX_WORD_AVAILABLE) {

			// statistically calculate the timings based on average of match timings
			RxPacket stat_packet;
			memset(stat_packet.word, 0, sizeof(stat_packet.word)); // clear to zero
			memcpy(stat_packet.word, rx.correl.last_match->word, strlen(rx.correl.last_match->word)); // copy match string

			uint8_t matches = 0;
			for (uint8_t i = 0; i < rx.correl.index; i++) {
				// ignore non-matches
				if (strcmp(stat_packet.word, rx.correl.received[i].word) != 0) {
					continue;
				}

				stat_packet.long_us = (stat_packet.long_us * matches + rx.correl.received[i].long_us) / (matches + 1);
				stat_packet.short_us = (stat_packet.short_us * matches + rx.correl.received[i].short_us) / (matches + 1);
				stat_packet.period_us = (stat_packet.period_us * matches + rx.correl.received[i].period_us) / (matches + 1);

				// increment match counter for average calcs
				matches++;
			}
			sprintf(usb_tx_buffer, "%" PRIu32 " word:%s len:%" PRIu16 " long_us:%" PRIu32 " short_us:%" PRIu32 " period_us:%" PRIu32 " logic:%u ignoresync:%u\r\n",
					status & (RX_WORD_AVAILABLE << 16), stat_packet.word, rx.correl.last_match->len,
					stat_packet.long_us, stat_packet.short_us, stat_packet.period_us,
					(unsigned int) rx.correl.last_match->logic, (unsigned int) rx.ignore_sync_bit);
			status &= ~(RX_WORD_AVAILABLE << 16);
		}
		pushUSB();
	}

	// check when last USB activity was, and turn off activity LED after timeout
	uint32_t delta = (HAL_GetTick() >= last_USB_time) ? HAL_GetTick() - last_USB_time : HAL_GetTick() + (UINT32_MAX - last_USB_time);
	if (delta > timeout_ms && HAL_GPIO_ReadPin(USB_ACT_GPIO_Port, USB_ACT_Pin) == GPIO_PIN_SET) {
		HAL_GPIO_WritePin(USB_ACT_GPIO_Port, USB_ACT_Pin, GPIO_PIN_RESET);
	}

	return 0;
}

void USER_error(void) {
	// blink LED based on error code 1's and 0's
}

void USER_shutdown(void) {

}

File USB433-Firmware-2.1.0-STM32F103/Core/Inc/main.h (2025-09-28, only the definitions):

#define USB_ACT_Pin GPIO_PIN_13
#define USB_ACT_GPIO_Port GPIOC
#define RX_EN_Pin GPIO_PIN_6
#define RX_EN_GPIO_Port GPIOB
#define TX_ACT_Pin GPIO_PIN_7
#define TX_ACT_GPIO_Port GPIOB

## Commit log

2025-09-28 Instructable Published
    [USB433-PCB-Design-KiCAD-B_Cu.gbr, USB433-PCB-Design-KiCAD-B_Mask.gbr, USB433-PCB-Design-KiCAD-B_Paste.gbr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]
2025-09-28 Updated Cost Estimate Sheet
    [USB433-BOM-Cost-Estimate.xlsx]

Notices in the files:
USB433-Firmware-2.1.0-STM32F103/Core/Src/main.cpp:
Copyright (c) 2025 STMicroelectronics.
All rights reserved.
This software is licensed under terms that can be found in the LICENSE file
